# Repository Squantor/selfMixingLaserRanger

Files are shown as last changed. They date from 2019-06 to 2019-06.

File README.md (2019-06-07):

# Self mixing laser ranging project
This project contains the hardware, software and experiment logs while developing a self mixing laser diode distance range and displacement measurement sensor. 
# 
This project is inspired by this excellent [youtube movie by applied science](https://youtu.be/MUdro-6u2Zg), it really got me thinking "can I turn this into an actual highly sensitive range sensor?". It has a bunch of thing in it for me:
* Analog circuit design
* Low noise electronics
* Signal processing
* Realtime processing
* LAZORS!!!

There are multiple applications I had in mind:
* Touch off sensor for CNC machines
* Sensitive sensor for seismography
* detecting expansion/shrinkage of walls in my house
* whatever sensitive measurement I need

Let see how far I get.

# Checking out
Submodules are used extensivly so do not forget to checkout with submodules, see command below.
```
https://github.com/Squantor/selfMixingLaserRanger.git
```
# Repository structure
* The [hardware](https://github.com/Squantor/selfMixingLaserRanger/tree/master/hardware) directory contains all the release and prototyping hardware.
* The [software](https://github.com/Squantor/selfMixingLaserRanger/tree/master/software) directory contains all the software for the ranger. Microcontroller of choice is the LPC824 as it is small, cheap and powerful enough for this application.
* The [documentation](https://github.com/Squantor/selfMixingLaserRanger/tree/master/documentation) directory contains lab notes, datasheets and other documentation.

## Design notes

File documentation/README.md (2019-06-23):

# Self mixing laser ranging lab notes
Here are the lab notes when developing the self mixing laser ranger.
# Lab notes
* [notes 2019-06-06](https://github.com/Squantor/selfMixingLaserRanger/tree/master/documentation/lab_notes_20190606/lab_notes_20190606.md)
* [notes 2019-06-23](https://github.com/Squantor/selfMixingLaserRanger/tree/master/documentation/lab_notes_20190623/lab_notes_20190623.md)

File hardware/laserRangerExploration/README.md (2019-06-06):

# Selfmixing laser ranger exploration circuit
This project exists to explore the circuitry and concept of a selfmixing laser. This is built up with large components and this will later be built out to a more complete design.
## TODO's
Still some things need to be done:
* schematic entry (WIP)
* PCB layout (TODO)
* Review with one night in between (TODO)
* Produce at [OSHPARK](https://oshpark.com/) (TODO)
* Assemble (TODO)
* Test & characterise (TODO)

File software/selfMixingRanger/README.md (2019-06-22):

# self mixing laser ranger software
This project peforms the main ranging functions for a selfmixing laser ranger.
## Checking out
use ```git clone --recurse-submodules https://github.com/Squantor/$(PROJECT).git``` to clone the repo and its submodules.
## Compiling
This project uses gnu make as its build system on a Linux platform. There are two build targets: release and debug. Release builds with optimizations and minimal debugging information. Debug builds with no optimization and full debug information.
```
$ make debug
$ make release
```
### Embedded targets
For debugging on embedded targets, the [Black Magic Probe](https://github.com/blacksphere/blackmagic/wiki) is used, scripts to use this debugger are present in the ```gdb_scripts``` directory. make can be used to invoke debugging:
```
make gdbusbdebug
make gdbusbrelease
```
This will build, if needed, the debug or release build respectivly and load it into the target.
```
make tpwrdisable
make tpwrenable
```
The black magic probe is capable of powering the target, these commands enable/disable this function.
### Depedencies
This program depends on a few subprojects I generaly use:
* [LPC82X chip library](https://github.com/Squantor/lpc_chip_82x.git)
* [minimal libc](https://github.com/Squantor/squantorLibC.git)
* [various embedded C functions](https://github.com/Squantor/squantorLibEmbeddedC.git)
This is automatically checked out when using ```git clone --recurse-submodules```.
## Usage
To use the software you need the following hardware:
* [Black magic probe](https://github.com/blacksphere/blackmagic)
* See hardware directory hardware types
# Additional information
Project just started
# TODO
The following tasks are still open:

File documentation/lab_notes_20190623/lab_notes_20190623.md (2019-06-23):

# Lab notes 20190625
Some additional progress has been made, started on a simple prototype to figure out what to measure and how.
## Setup
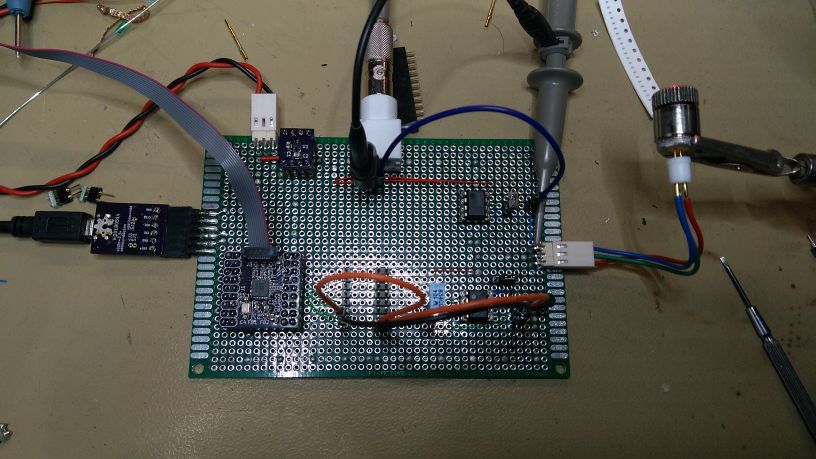
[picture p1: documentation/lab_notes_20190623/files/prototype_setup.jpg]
Prototype board


Prototyping board with:
* constant current sink driving the laser diode
* transimpedance amplifier for the laser photodiode
* LPC824 microcontroller breakout
* USB to uart
* debugger connection with a black box probe (not on picture)

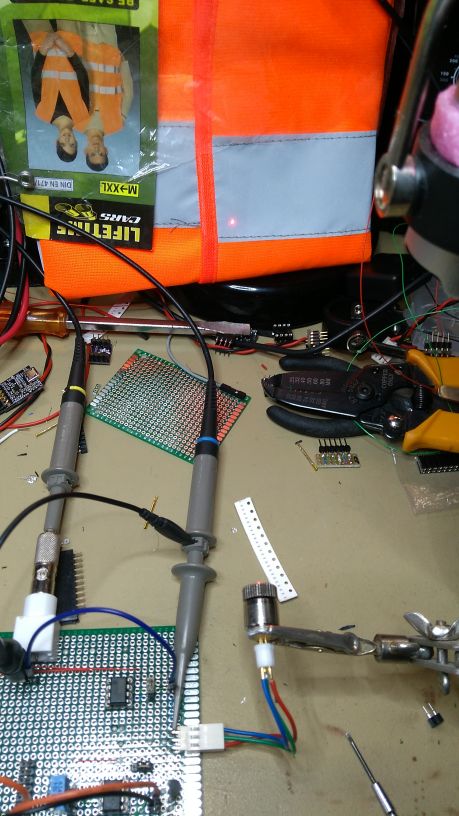
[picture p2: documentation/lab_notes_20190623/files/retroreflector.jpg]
Shining laser on improvised retroreflector


Shining a laser on the only retroreflector I have in house.

## Laser diode current drive
Currently implemented as a constant current sink with a 10 Ohm resistor and a [TLC271 CMOS opamp](http://www.ti.com/product/TLC271).

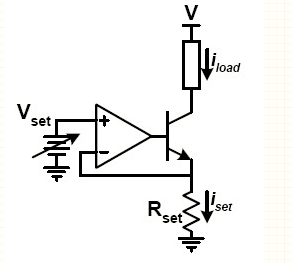
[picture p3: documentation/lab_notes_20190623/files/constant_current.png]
Constant current source


The laser diode is the load.

 The reference voltage is created by using the 3.3V that usually supplies the microcontroller and that feeds a 100K trimpot in series with a resistor to scale down the current setting voltage not to something full range. The 3.3V would imply a current of 330mA, way too much for this diode. It is settable from 0 to 600mV, that means settable from 0 to 60mV.
### Final implementation
Next step is to replace to control the current loop of the laser diode via the microcontroller. A filtered PWM signal can drive the bipolar transistor and the current can be sensed by the ADC directly.
## Photodiode sense
Photodiode of the laser is sensed via a transimpedance amplifier using a 10KOhm feedback resistor with a 22pF capacitor parallel, the opamp chosen is one half of a [TLC272](http://www.ti.com/product/TLC272). The topology is not completely standard. The photodiode is connected to highest voltage rail, so a classical transimpedance amplifier would need to drive its output negative to ground, not really possible in a single supply environment. So the non inverting input was connected to the reference so the output now goes from 3.3V to 0V depending on the light falling on the photodiode, perfect for sensing with a a microcontroller.

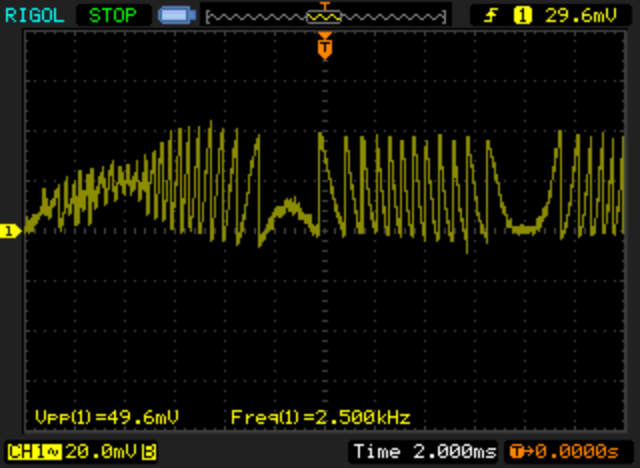
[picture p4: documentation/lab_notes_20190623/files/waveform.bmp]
Photodiode output AC coupled


This is starting to look like something that applied science showed.

## debug connections
I can easely hook up various parts to various ADC channels of the microcontroller for monitoring. The LPC824 is quick and precise enough to perform a few functions. The coax connections above is useful to hooking a oscilloscope up to signals of interest without messing around with probes.

## next steps
* Create a Opamp AC amplifier that will filter out the AC signal and amplify it some more, gain of 10 should be okay as the output of the transimpedance amplifier is about 100mV AC coupled.
* Capture DC and AC from the photodiode with the microcontroller ADC
* Change current control to be microcontroller controlled with just a PWM DAC and bipolar transistor.
* Start with initial schematic in kicad

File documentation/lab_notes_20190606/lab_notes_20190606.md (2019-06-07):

# Lab notes 20190606
## Diode verification
Started by measuring my [ebay laser diodes](https://www.ebay.com/itm/223016401263) [ADL-65052TL](https://github.com/Squantor/selfMixingLaserRanger/tree/master/documentation/datasheets/ADL-65052TL_6-2D-LD65-004_REV01.pdf) if they really are diodes with a photodiode feedback. What I know from experience is that the low power diodes (5mw) usually have a photodiode as the margins between not working, lasing and destructions are pretty small and sensitive to temperature. But best to make sure this is the real deal.
## Determine pinout
The Laserfaq has a [good guide](http://www.repairfaq.org/sam/laserdio.htm#diodct2) in figuring out the pinout of unknown laser diodes. This worked better then expected in my case, one difference was. The photodiode was about 0.4V output when I shine a pretty bright LED on it but the laser diode output was almost a volt! Either I shone into it quite well or this diode is a bit more sensitive. They do mention that you should shine a tungsten bulb lamp on it, not a white LED. In any case, the pinout matched the datasheet.
## Firin my lazor!
Okay, now I have that meme out of the way. It is time to determine lasing current of the diode.

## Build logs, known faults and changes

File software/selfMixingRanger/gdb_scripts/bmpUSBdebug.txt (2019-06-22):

file bin/debug/template_microcontroller.elf
target extended-remote /dev/ttyBmpGdb0
monitor tpwr enable
shell sleep 1
monitor swdp_scan
attach 1
set mem inaccessible-by-default off
set {int}0x40048000 = 2
load bin/debug/template_microcontroller.elf
set {int}0x40048000 = 2
compare-sections
b main

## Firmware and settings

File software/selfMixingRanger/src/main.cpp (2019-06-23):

/*
The MIT License (MIT)

Copyright (c) 2018 Bart Bilos

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
THE SOFTWARE IS PROVIDED "AS IS", WITHOUT WARRANTY OF ANY KIND, EXPRESS OR
IMPLIED, INCLUDING BUT NOT LIMITED TO THE WARRANTIES OF MERCHANTABILITY,
FITNESS FOR A PARTICULAR PURPOSE AND NONINFRINGEMENT. IN NO EVENT SHALL THE
AUTHORS OR COPYRIGHT HOLDERS BE LIABLE FOR ANY CLAIM, DAMAGES OR OTHER
LIABILITY, WHETHER IN AN ACTION OF CONTRACT, TORT OR OTHERWISE, ARISING FROM,
OUT OF OR IN CONNECTION WITH THE SOFTWARE OR THE USE OR OTHER DEALINGS IN THE
SOFTWARE.
*/
/*
Main program entry/file.
*/

#include "chip.h"
#include <cr_section_macros.h>
#include <board.hpp>
#include <stream_uart.hpp>
#include <strings.hpp>
#include <print.h>
#include <prompt_mini.h>
#include <command_mini.h>
#include <commands.hpp>

char promptBuf[5];
result cmdlineParse(char *cmdline);

promptData_t rangerPromptData = 
{
    promptBuf,
    0,
    sizeof(promptBuf),
    cmdlineParse,
};

volatile uint32_t ticks = 0;
volatile bool sequenceComplete, thresholdCrossed;

extern "C"
{
    void SysTick_Handler(void)
    {
        ticks++;
        /* Manual start for ADC conversion sequence A */
        Chip_ADC_StartSequencer(LPC_ADC, ADC_SEQA_IDX);
    }

    void ADC_SEQA_IRQHandler(void)
    {
        uint32_t pending;

        /* Get pending interrupts */
        pending = Chip_ADC_GetFlags(LPC_ADC);

        /* Sequence A completion interrupt */
        if (pending & ADC_FLAGS_SEQA_INT_MASK) {
            sequenceComplete = true;
        }

        /* Clear any pending interrupts */
        Chip_ADC_ClearFlags(LPC_ADC, pending);
    }
}

result cmdlineParse(char *const cmdline)
{
    return commandInterpret(rangerCommands, cmdline);
}

int main(void)
{
    boardInit(); 

    SysTick_Config(SystemCoreClock / TICKRATE_HZ);
    
    dsPuts(&streamUart, strHello);
    Chip_ADC_EnableSequencer(LPC_ADC, ADC_SEQA_IDX);

    while (1)
    {
        promptProcess(&rangerPromptData, &streamUart);
        
        /* Is a conversion sequence complete? */
        if(sequenceComplete) 
        {
            sequenceComplete = false;

            /* Get raw sample data for channels 0-11 */
            for (uint16_t i = 0; i < 12; i++) {
                uint32_t rawSample = Chip_ADC_GetDataReg(LPC_ADC, i);

                /* Show some ADC data */
                if (rawSample & (ADC_DR_OVERRUN | ADC_SEQ_GDAT_DATAVALID)) 
                {
                    printDecNzU16(&streamUart, i);
                    dsPuts(&streamUart, strIs);
                    printDecU16(&streamUart, (uint16_t) ADC2MILLIVOLT(ADC_DR_RESULT(rawSample)));
                    dsPuts(&streamUart, strSep);
                }
            }
            dsPuts(&streamUart, strCrLf);
        }
    }

    return 0 ;
}

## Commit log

2019-05-29 added constant current laser driver initial project
    [laserConstantCurrent.kicad_pcb, laserConstantCurrent.sch]
2019-05-29 updated date
    [laserConstantCurrent.kicad_pcb, laserConstantCurrent.sch]
2019-06-06 just start with a more or less complete schematic
    [laserConstantCurrent.kicad_pcb, laserConstantCurrent.sch]
2019-06-06 started with exploration board of the laser ranger
    [laserRangerExploration.kicad_pcb, laserRangerExploration.sch]
2019-06-06 updated versionnumber
    [laserRangerExploration.sch]
2019-06-06 added initial few schematic blocks
    [laserRangerController.sch, laserRangerExploration.sch, laserRangerPower.sch]
2019-06-06 further submodule additions
    [laserRangerDriver.sch, laserRangerExploration.sch, laserRangerPower.sch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]
2019-06-06 small pcb update
    [laserRangerExploration.kicad_pcb]
2019-06-22 copied stuff from ADC evaluator
